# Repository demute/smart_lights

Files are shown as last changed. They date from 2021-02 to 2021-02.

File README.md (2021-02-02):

# smart_lights
This is a prototype for implementing smart lights: Lights that are saving
energy by selectively controlling which lights are on. The prototype is based
on the [Turtle Board from Radio Shuttle](https://www.radioshuttle.de/en/turtle-en/turtle-board-en/).
A radar motion detector has been added to the board, designed around the
cdm324 sensor, schematic and layout made in KiCAD and Inspired by
[limpkin](https://www.limpkin.fr/index.php?post/2017/02/22/Making-the-Electronics-for-a-24GHz-Doppler-Motion-Sensor).
The daughter board has one micro-usb connector for power and one usb-a connector
for a usb-lamp, which would be replaced with a zhaga socket on a real product.

The idea is this: Suppose luminaires are installed along a road and suppose
all luminaires are turned off. Now, if one luminaire detects motion, it will
lit itself up but also adjacent luminaires. Since adjacent luminaires are lit
up, the perceived feeling would be that the lights are on all the time.

street

The hardware for making this work looks like this:

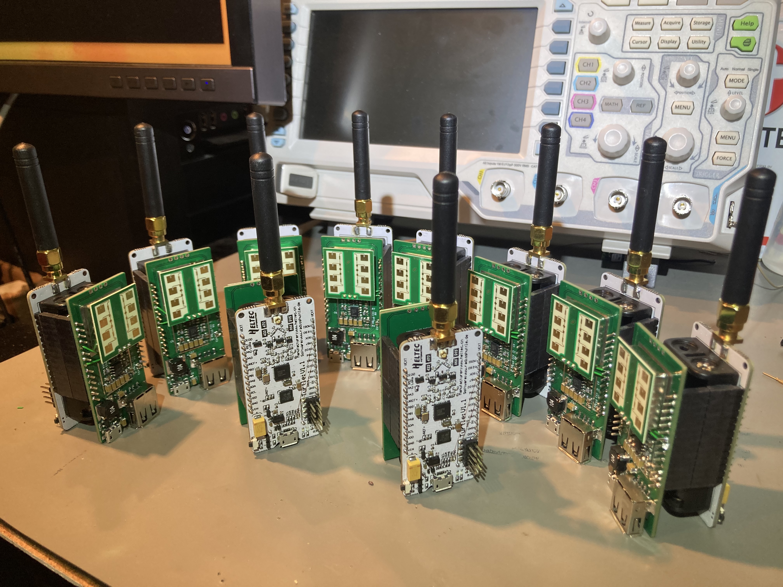
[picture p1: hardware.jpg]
hardware


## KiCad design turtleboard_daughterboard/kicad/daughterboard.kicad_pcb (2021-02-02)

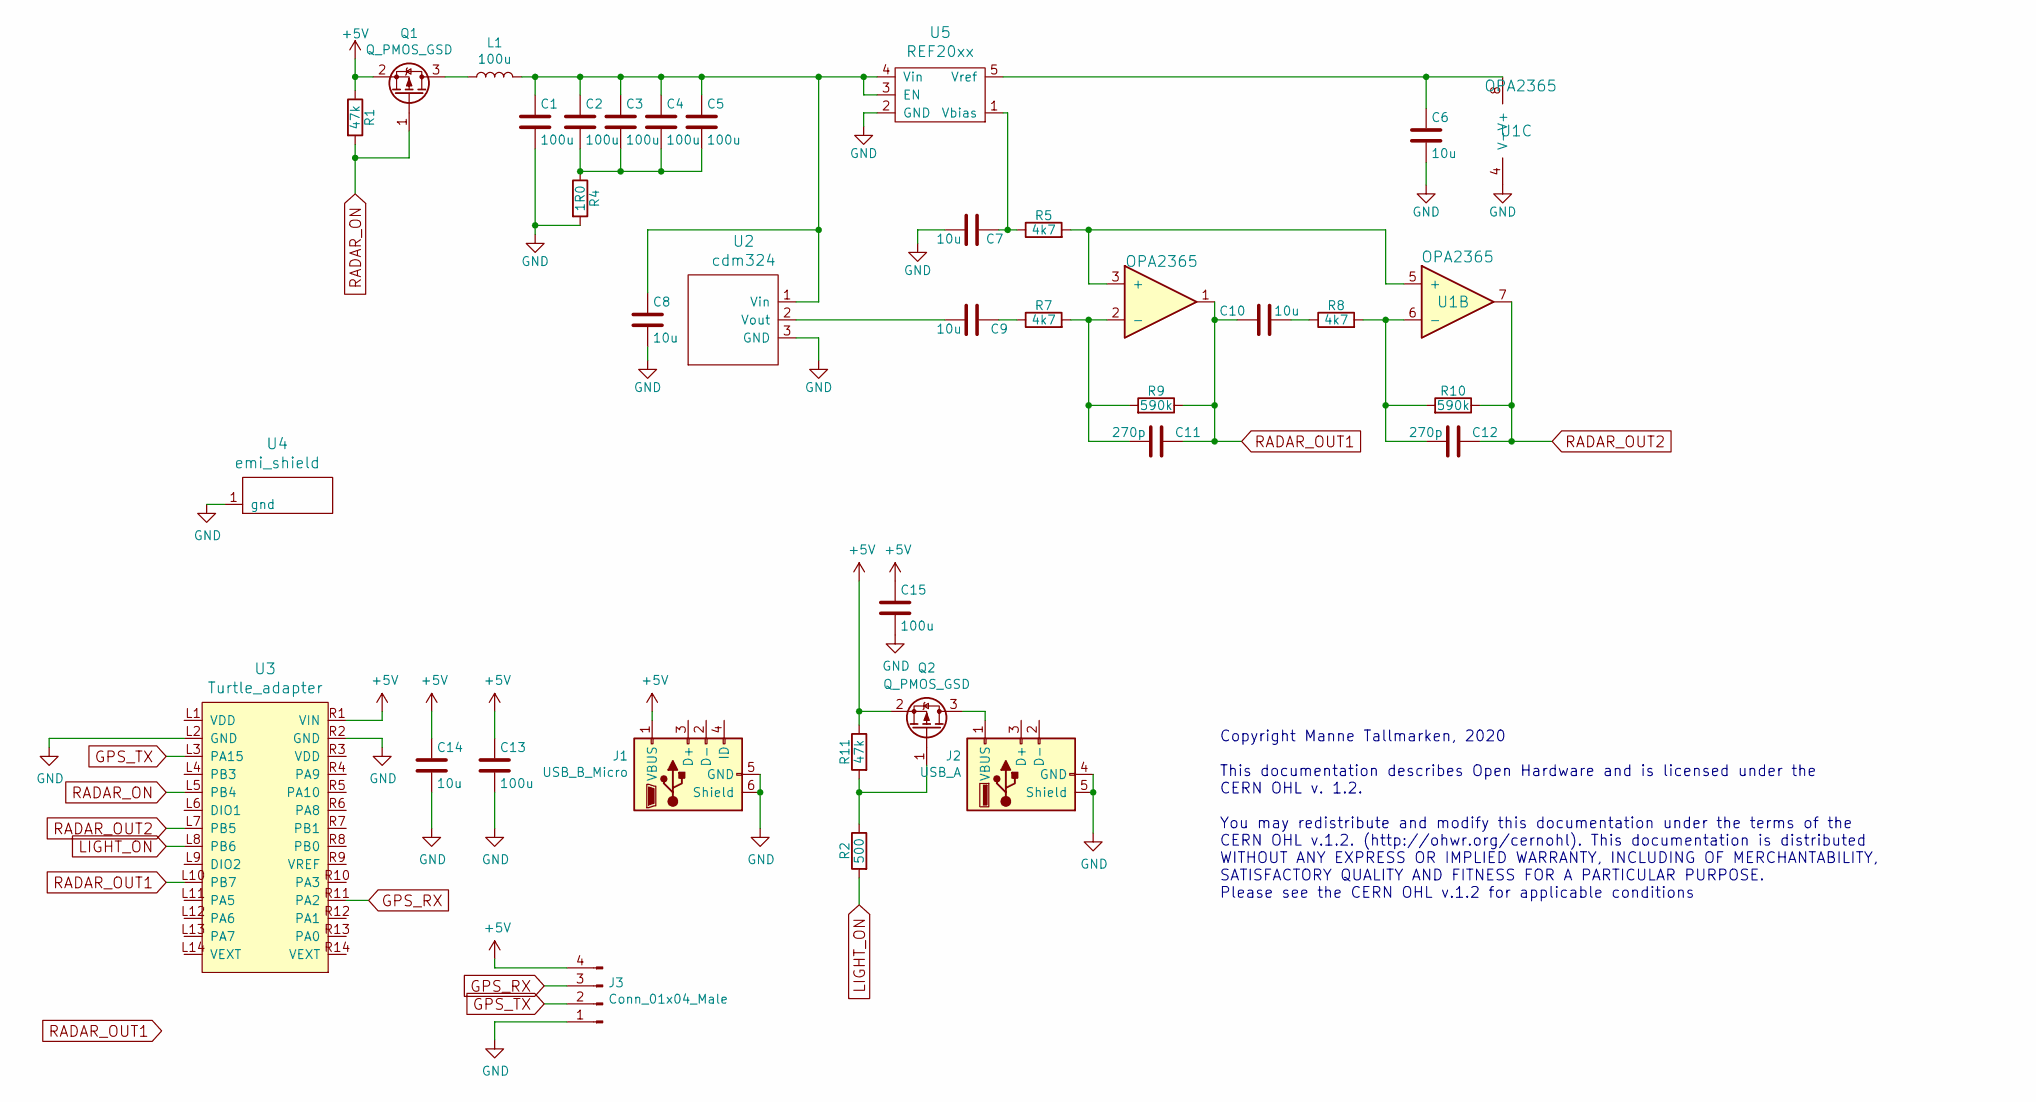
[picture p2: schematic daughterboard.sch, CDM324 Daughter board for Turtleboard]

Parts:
C1, C2, C3, C4, C5, C13, C15: 100u; C_1206_3216Metric_Pad1.42x1.75mm_HandSolder
C6, C7, C8, C9, C10, C14: 10u; C_0805_2012Metric
C11, C12: 270p; C_0603_1608Metric
J1: USB_B_Micro; usb-micro
J2: USB_A; usb-a
J3: Conn_01x04_Male; PinSocket_1x04_P2.54mm_Horizontal
L1: 100u; pa4319
Q1, Q2: Q_PMOS_GSD; SOT-23
R1, R11: 47k; R_0603_1608Metric
R2: 500; R_0603_1608Metric
R4: 1R0; R_0603_1608Metric
R5, R7, R8: 4k7; R_0603_1608Metric
R9, R10: 590k; R_0603_1608Metric
U1: OPA2365; SOIC-8_3.9x4.9mm_P1.27mm
U2: cdm324
U3: Turtle_adapter; turtleboard
U4: emi_shield; sms-202c
U5: REF20xx; SOT-23-5

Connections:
+5V: C13.1, C14.1, C15.1, J1.1 (VBUS), J3.4, Q1.2 (S), Q2.2 (S), R1.1, R11.1, U3.R1 (VIN)
GND: C1.2, C6.2, C7.2, C8.2, C13.2, C14.2, C15.2, J1.5 (GND), J1.6 (Shield), J2.4 (GND), J2.5 (Shield), J3.1, R4.2, U1.4 (V-), U2.3 (GND), U3.L2 (GND), U3.R2 (GND), U4.1, U5.2 (GND)
GPS_RX: J3.3, U3.R11 (PA2)
GPS_TX: J3.2, U3.L3 (PA15)
LIGHT_ON: R2.2, U3.L8 (PB6)
unnamed: C1.1, C2.1, C3.1, C4.1, C5.1, C8.1, L1.2, U2.1 (Vin), U5.3 (EN), U5.4 (Vin)
unnamed: C2.2, C3.2, C4.2, C5.2, R4.1
unnamed: C6.1, U1.8 (V+), U5.5 (Vref)
unnamed: C7.1, R5.1, U5.1 (Vbias)
unnamed: C9.1, R7.1
unnamed: C9.2, U2.2 (Vout)
unnamed: C10.2, R8.1
unnamed: C11.2, R7.2, R9.2, U1.2 (-)
unnamed: C12.2, R8.2, R10.2, U1.6 (-)
unnamed: J2.1 (VBUS), Q2.3 (D)
unnamed: L1.1, Q1.3 (D)
unnamed: Q2.1 (G), R2.1, R11.2
unnamed: R5.2, U1.3 (+), U1.5 (+)
RADAR_ON: Q1.1 (G), R1.2, U3.L5 (PB4)
RADAR_OUT1: C10.1, C11.1, R9.1, U1.1, U3.L10 (PB7)
RADAR_OUT2: C12.1, R10.1, U1.7, U3.L7 (PB5)

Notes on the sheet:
Copyright Manne Tallmarken, 2020 This documentation describes Open Hardware and is licensed under the CERN OHL v. 1.2. You may redistribute and modify this documentation under the terms of the CERN OHL v.1.2. (http://ohwr.org/cernohl). This documentation is distributed WITHOUT ANY EXPRESS OR IMPLIE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

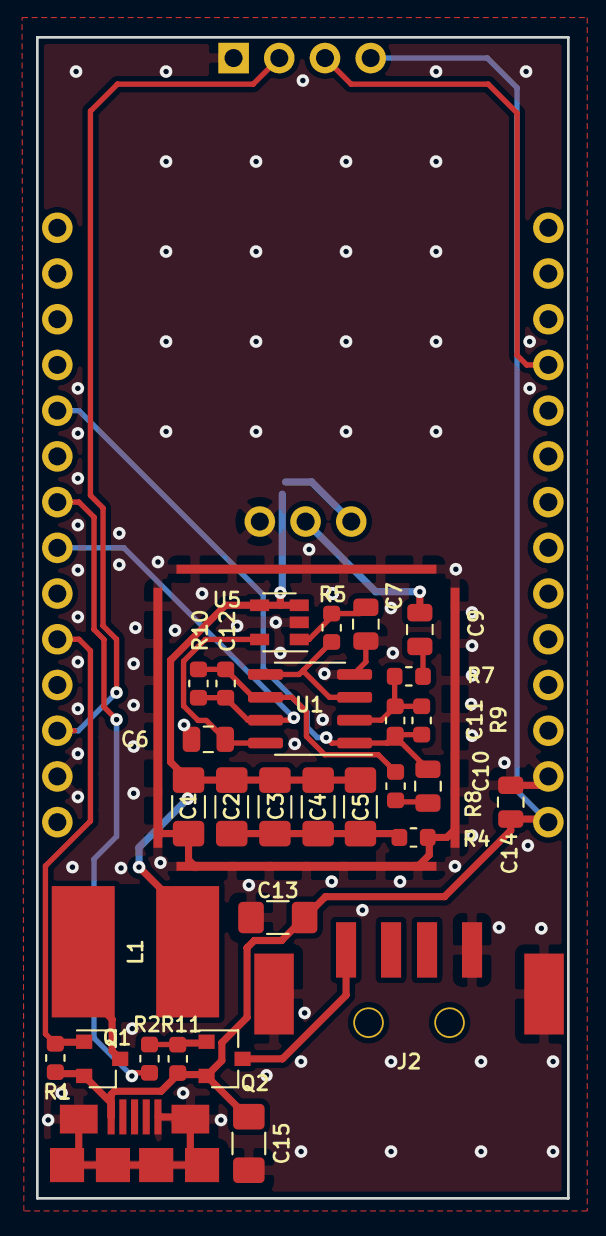
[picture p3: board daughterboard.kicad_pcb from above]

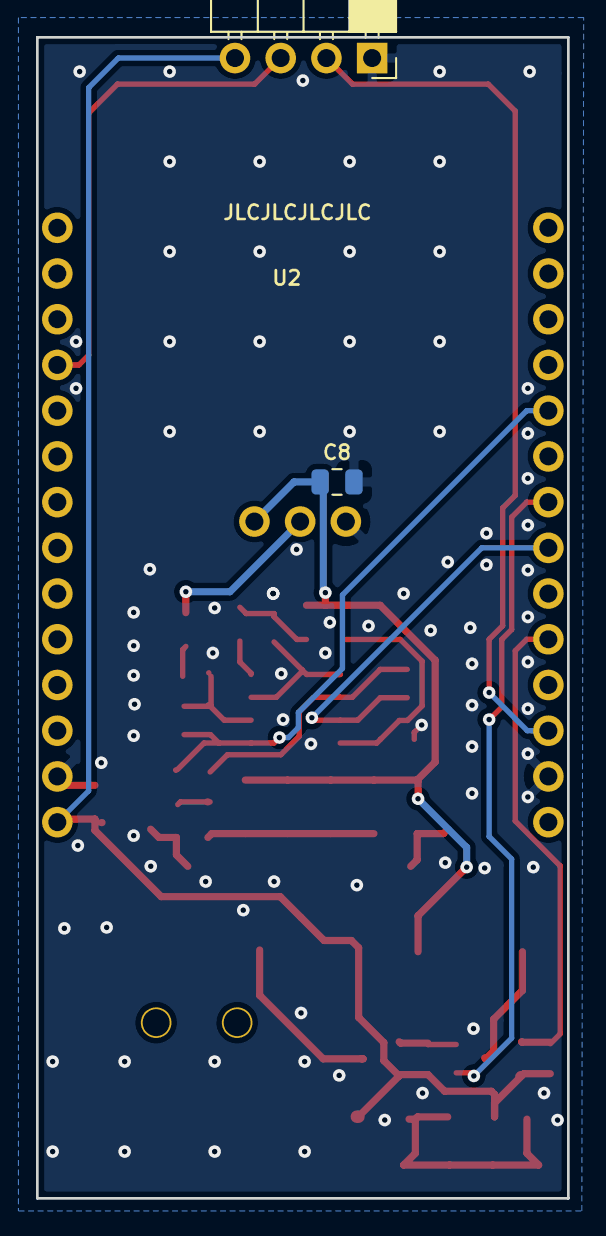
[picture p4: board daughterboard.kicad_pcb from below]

Board: 4 copper layers, 29.5 x 64.5 mm, 35 parts (4 on the bottom side), 21 nets.

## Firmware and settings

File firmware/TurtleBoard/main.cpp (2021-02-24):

/*
 * TODO:
 * Compiler Date/Time is not set correctly on startup using gcc
 */
#include "main.h"
#include "RadioTest.h"
#include <vector>
#include "ProgramInterface.h"
#include "mbed.h"
#include "accumulator.h"
#include "adc.h"
#include "detection_algorithm.h"
#include "SlightlightProtocol.h"
#include "timestamp.h"

#ifdef  FEATURE_NVPROPERTY
#include <NVPropertyProviderInterface.h>
#include "NVProperty.h"
#endif

#define MOTION_TIMEOUT_US (40 * 1000000)

// saker vi behöver till nästa rev:
// lågpassfilter på båda adc-ingångarna
// sladdarna rätt dragna

extern void RunCommands(int timeout_ms);

DigitalOut greenLED(PB_7);
DigitalOut redLED(PB_5);
InterruptIn buttonIntr(USER_BUTTON);

DigitalInOut radarOff (PB_4);
DigitalInOut lightOff (PB_6);

uint16_t deviceId = 0;
uint64_t lastStateChangeTsp = 0;
uint64_t lastTurnOnTsp = 0;
uint64_t lastMotionTsp = 0;
uint64_t lastTurnOffTsp = 0;
uint64_t lastTransmissionTsp = 0;
int      nodeState = STATE_OFF;

void turn_light_on (void)
{
    lightOff.output ();
    lightOff = 0;
    //redLED = 1;
}

void turn_light_off (void)
{
    lightOff.input ();
    //redLED = 0;
}

int update_node_state (uint8_t newState)
{
    switch (newState)
    {
     case STATE_OFF:                 turn_light_off (); break;
     case STATE_ON_DUE_TO_MOTION:    turn_light_on (); break;
     case STATE_ON_DUE_TO_NEIGHBOUR: turn_light_on (); break;
     default: dprintf ("unknown state"); return 0;
    }
    int stateChanged = (nodeState != newState);
    nodeState = newState;
    if (stateChanged)
        lastStateChangeTsp = get_timestamp_in_us ();
    return stateChanged;
}

void on_motion_detected (int32_t powerAboveBackround_s1677721600)
{
    dprintf ("MOTION DETECTED! powerAboveBackround_s1677721600: %lf", powerAboveBackround_s1677721600 * 1e-6);
    lastMotionTsp = get_timestamp_in_us ();
    if (lastMotionTsp == 0)
        lastMotionTsp = 1;
}

void switchInput(void) {
    on_motion_detected (-1);
}

int get_node_id (uint16_t addr)
{                                    //    0       1       2       3       4       5       6       7       8       9
    static uint16_t nodes[NUM_NODES] = {0x2bc5, 0x2bc6, 0x2bc7, 0x2bc8, 0x2bc9, 0x2bca, 0x2bcb, 0x2bce, 0x2bcf, 0x2bd0};
    for (int id=0; id<NUM_NODES; id++)
        if (nodes[id] == addr)
            return id;
    return -1;
}

int main()
{
    /*
     * inits the Serial or USBSerial when available (230400 baud).
     * If the serial uart is not is not connected it swiches to USB Serial
     * blinking LED means USBSerial detected, waiting for a connect.
     * It waits up to 30 seconds for a USB terminal connections 
     */

    NVProperty prop;
    uint32_t deviceIdU32 = prop.GetProperty(prop.LORA_DEVICE_ID, 0);
    deviceId = (uint16_t) deviceIdU32;
    if (deviceId != deviceIdU32)
        deviceId = 0xffff; // if we have any nodes with this id in the system we know 16 bits is not enough (and we need to increase)

    detection_algorithm_init (on_motion_detected);
    InitSerial(15*1000, &greenLED, &buttonIntr);
    RunStartup();
    adc_init ();

    dprintf("Welcome to RadioShuttle v%d.%d deviceId:%04lx", RS_MAJOR, RS_MINOR, deviceIdU32);

#if defined (USER_BUTTON_RISE)
    buttonIntr.rise(& switchInput);
#else
    //buttonIntr.fall(& switchInput);
#endif

    //RunCommands(10000);	// check 10 secs for any commands

    radarOff.output ();
    radarOff = 0;

    update_node_state (STATE_OFF);

    uint16_t adcVal=0;

    slightlight_init ();

    extern NodeCache cache[NUM_NODES];
    int id = get_node_id (deviceId);

    while(true)
    {
        slightlight_poll ();
        //uint32_t elapsedUsSinceTurnOn = (uint32_t) (get_timestamp_in_us () - lastTurnOnTsp);
        //if (transmitting)
        //{
        //    if (elapsedUsSinceTurnOn < 5000000)
        //        wait_ms (500);
        //    //dprintf ("curbuf: %d", adc_buf_len ());
        //    adc_empty_buffer ();
        //    //dprintf ("newbuf: %d", adc_buf_len ());
        //}

        static uint64_t lastPrintTsp = us_ticker_read ();
        if (us_ticker_read () - lastPrintTsp > 1000000)
        {
            lastPrintTsp = us_ticker_read ();
            char header[32] = {0};
            char states[32] = {0};
            char *ph = header, *ps = states;
            cache[id].packet.state = nodeState;
            for (int id2=0; id2<10; id2++)
            {
                char s;
                switch (cache[id2].packet.state)
                {
                 case STATE_UNDEFINED:
                     continue;
                 case STATE_OFF:
                     s = '-';
                     break;
                 case STATE_ON_DUE_TO_MOTION:
                 {
                     uint32_t timeSincePacketReceived = (uint32_t) ((get_timestamp_in_us () - cache[id2].tsp));
                     uint32_t timeSinceLastMotion = timeSincePacketReceived + cache[id2].packet.timeSinceLastMotion * 1000000;
                     s = (timeSinceLastMotion < MOTION_TIMEOUT_US) ? '#' : '-';
                     break;
                 }
                 case STATE_ON_DUE_TO_NEIGHBOUR:
                     s = '+';
                     break;
                 default:
                     s = '?';
                     break;
                }

                ph += sprintf (ph, "%s%d", (id2?" ":""), id2);
                ps += sprintf (ps, "%s%c", (id2?" ":""), s);
            }
            dprintf ("Luminaire id:    %s", header);
            dprintf ("Luminaire state: %s", states);
        }

        uint64_t tsp = get_timestamp_in_us ();
        int neighbourDetectedMotion = 0;
        int leftNeighbourId  = id - 1;
        int rightNeighbourId = id + 1;
        while (leftNeighbourId >= 0 && cache[leftNeighbourId].packet.state == STATE_UNDEFINED)
            leftNeighbourId--;
        while (rightNeighbourId < NUM_NODES && cache[rightNeighbourId].packet.state == STATE_UNDEFINED)
            rightNeighbourId++;

        if (leftNeighbourId >= 0)
        {
            uint32_t timeSincePacketReceived = (uint32_t) ((get_timestamp_in_us () - cache[leftNeighbourId].tsp));
            uint32_t timeSinceLastMotion     = timeSincePacketReceived + cache[leftNeighbourId].packet.timeSinceLastMotion * 1000000;
            if (timeSinceLastMotion < MOTION_TIMEOUT_US)
                neighbourDetectedMotion = 1;
        }
        if (rightNeighbourId < NUM_NODES)
        {
            uint32_t timeSincePacketReceived = (uint32_t) ((get_timestamp_in_us () - cache[rightNeighbourId].tsp));
            uint32_t timeSinceLastMotion     = timeSincePacketReceived + (uint32_t) cache[rightNeighbourId].packet.timeSinceLastMotion * 1000000;
            if (timeSinceLastMotion < MOTION_TIMEOUT_US)
                neighbourDetectedMotion = 1;
        }

        if (tsp - lastMotionTsp < MOTION_TIMEOUT_US)
        {
            int lastState = nodeState;
            if (update_node_state (STATE_ON_DUE_TO_MOTION))
            {
                dprintf ("changed state to STATE_ON_DUE_TO_MOTION");
                if (lastState == STATE_OFF)
                    lastTurnOnTsp = tsp;
            }
        }
        else if (neighbourDetectedMotion)
        {
            int lastState = nodeState;
            if (update_node_state (STATE_ON_DUE_TO_NEIGHBOUR))
            {
                dprintf ("changed state to STATE_ON_DUE_TO_NEIGHBOUR");
                if (lastState == STATE_OFF)
                    lastTurnOnTsp = tsp;
            }
        }
        else
        {
            if (update_node_state (STATE_OFF))
            {
                lastTurnOffTsp = tsp;
                dprintf ("TURNING LIGHT OFF");
            }
        }

        if (adc_get_and_reset_oflow_flag ())
        {
            for (int i=0; i<40; i++)
                dprintf ("OVERFLOW");
        }

        int transientsMayExist =  (tsp - lastTurnOnTsp       < 500000) ||
                                  (tsp - lastTurnOffTsp      < 500000) ||
                                  (tsp - lastTransmissionTsp < 500000);

        if (transientsMayExist)
            adc_empty_buffer ();
        else
        {
            int i=0;
            for (i=0; i<ADC_BUF_SIZE && adc_get_noblock (& adcVal); i++)
                detection_algorithm_feed (adcVal);
            if (i == ADC_BUF_SIZE)
                dprintf ("queue_pop error? oflow=%d", adc_get_and_reset_oflow_flag ());
        }

        wait_ms (1);
    }
}

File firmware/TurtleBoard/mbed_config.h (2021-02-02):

/*
 * mbed SDK
 * Copyright (c) 2017 ARM Limited
 *
 * Licensed under the Apache License, Version 2.0 (the "License");
 * you may not use this file except in compliance with the License.
 * You may obtain a copy of the License at
 *
 * http://www.apache.org/licenses/LICENSE-2.0
 *
 * Unless required by applicable law or agreed to in writing, software
 * distributed under the License is distributed on an "AS IS" BASIS,
 * WITHOUT WARRANTIES OR CONDITIONS OF ANY KIND, either express or implied.
 * See the License for the specific language governing permissions and
 * limitations under the License.
 */

// Automatically generated configuration file.
// DO NOT EDIT, content will be overwritten.

#ifndef __MBED_CONFIG_DATA__
#define __MBED_CONFIG_DATA__

// Configuration parameters
#define CLOCK_SOURCE                                                      USE_PLL_MSI                             // set by target:NUCLEO_L432KC
#define LPTICKER_DELAY_TICKS                                              0                                       // set by target:NUCLEO_L432KC
#define MBED_CONF_DRIVERS_QSPI_CSN                                        QSPI_FLASH1_CSN                         // set by library:drivers
#define MBED_CONF_DRIVERS_QSPI_IO0                                        QSPI_FLASH1_IO0                         // set by library:drivers
#define MBED_CONF_DRIVERS_QSPI_IO1                                        QSPI_FLASH1_IO1                         // set by library:drivers
#define MBED_CONF_DRIVERS_QSPI_IO2                                        QSPI_FLASH1_IO2                         // set by library:drivers
#define MBED_CONF_DRIVERS_QSPI_IO3                                        QSPI_FLASH1_IO3                         // set by library:drivers
#define MBED_CONF_DRIVERS_QSPI_SCK                                        QSPI_FLASH1_SCK                         // set by library:drivers
#define MBED_CONF_DRIVERS_UART_SERIAL_RXBUF_SIZE                          256                                     // set by library:drivers
#define MBED_CONF_DRIVERS_UART_SERIAL_TXBUF_SIZE                          256                                     // set by library:drivers
#define MBED_CONF_PLATFORM_CRASH_CAPTURE_ENABLED                          0                                       // set by library:platform
#define MBED_CONF_PLATFORM_CTHUNK_COUNT_MAX                               8                                       // set by library:platform
#define MBED_CONF_PLATFORM_DEFAULT_SERIAL_BAUD_RATE                       9600                                    // set by library:platform
#define MBED_CONF_PLATFORM_ERROR_ALL_THREADS_INFO                         0                                       // set by library:platform
#define MBED_CONF_PLATFORM_ERROR_FILENAME_CAPTURE_ENABLED                 0                                       // set by library:platform
#define MBED_CONF_PLATFORM_ERROR_HIST_ENABLED                             0                                       // set by library:platform
#define MBED_CONF_PLATFORM_ERROR_HIST_SIZE                                4                                       // set by library:platform
#define MBED_CONF_PLATFORM_ERROR_REBOOT_MAX                               1                                       // set by library:platform
#define MBED_CONF_PLATFORM_FATAL_ERROR_AUTO_REBOOT_ENABLED                0                                       // set by library:platform
#define MBED_CONF_PLATFORM_FORCE_NON_COPYABLE_ERROR                       0                                       // set by library:platform
#define MBED_CONF_PLATFORM_MAX_ERROR_FILENAME_LEN                         16                                      // set by library:platform
#define MBED_CONF_PLATFORM_MINIMAL_PRINTF_ENABLE_64_BIT                   1                                       // set by library:platform
#define MBED_CONF_PLATFORM_MINIMAL_PRINTF_ENABLE_FLOATING_POINT           0                                       // set by library:platform
#define MBED_CONF_PLATFORM_MINIMAL_PRINTF_SET_FLOATING_POINT_MAX_DECIMALS 6                                       // set by library:platform
#define MBED_CONF_PLATFORM_POLL_USE_LOWPOWER_TIMER                        0                                       // set by library:platform
#define MBED_CONF_PLATFORM_STDIO_BAUD_RATE                                9600                                    // set by library:platform
#define MBED_CONF_PLATFORM_STDIO_BUFFERED_SERIAL                          0                                       // set by library:platform
#define MBED_CONF_PLATFORM_STDIO_CONVERT_NEWLINES                         0                                       // set by library:platform
#define MBED_CONF_PLATFORM_STDIO_CONVERT_TTY_NEWLINES                     0                                       // set by library:platform
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

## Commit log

2021-02-02 add kicad files
    [cdm324-B_Cu.gbr, cdm324-B_Mask.gbr, cdm324-B_SilkS.gbr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]
2021-02-24 better state handling, improved stability for sending and receiving messages, improved detection algorithm
    [adc.cpp, main.cpp, mutils.cpp]
